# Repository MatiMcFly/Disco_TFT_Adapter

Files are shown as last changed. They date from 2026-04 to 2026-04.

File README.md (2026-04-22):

# 🖥️ Discovery Board TFT Adapter

This project contains the KiCad hardware design for a TFT display adapter designed to connect a TFT panel (GX040R-30MB-A1ICNL9707) to an STMicroelectronics STM32H747I Discovery Kit.

The adapter board includes circuitry to interface the display with the Discovery board, including a TPS61169 LED driver for the display backlight.

## 🔌 Connectivity between DISCO board and GX040R display

- according to the manufacturer, the display has to be connected as follows: Board (DP/N0) to LCD (DP/N1) and (DP/N1) to (DP/N3). A previous revision A of this board has gotten this wrong. D0 of the board has been connected to D0 of the TFT and D1 of the board to D1 of the TFT.
- CTP (capacitive touch display) functionalities (I2C, INT, ...) are not used

## 📚 Datasheets and Documentation

All relevant datasheets, manuals, and reference documents can be found in this [Google Drive folder](https://drive.google.com/drive/folders/1Etk3SSePW-oP0WRn9YrgEl5WCk2nYt2u?usp=sharing).

### 📋 Document Overview:

* **`disco_tft_adapter.pdf`** - The schematic for this adapter board project.
* **`GX040R-30MB-A1(V1).pdf`** - Datasheet for the TFT display panel used with this adapter.
* **`ICNL_9707_Datasheet...pdf`** - Datasheet for the ICNL9707, the display driver IC integrated into the TFT panel (might be obsolete)
* **`tps61169.pdf`** - Datasheet for the Texas Instruments TPS61169, the WLED driver IC used on this adapter for the display backlight.
* **`stm32h747-datasheet.pdf`** - Electrical characteristics and pinout for the STM32H747 microcontroller.
* **`stm32h747-ref-manual.pdf`** - Detailed reference manual for the STM32H747 MCU peripherals and registers.
* **`stm32h747-prog-manual.pdf`** - Programming manual detailing the architecture and instruction set for the STM32H747.
* **`mb1166-default-a09-schematic.pdf`** - Schematic for the MB1166 base board of the STM32H7 Discovery kit.
* **`mb1248-h747i-d03-schematic.pdf`** - Schematic for the MB1248 CPU board of the STM32H747I-DISCO kit.
* **`um2411-discovery-kit-...pdf`** - Official user manual (UM2411) for the STM32H747I-DISCO Discovery kit.
* **`JD9365DA-H3_User_Guide_Preliminary_V0.00_20200827.pdf` - User guide for the display driver. This is the last version that was received from the contact person at the display manufacturer.

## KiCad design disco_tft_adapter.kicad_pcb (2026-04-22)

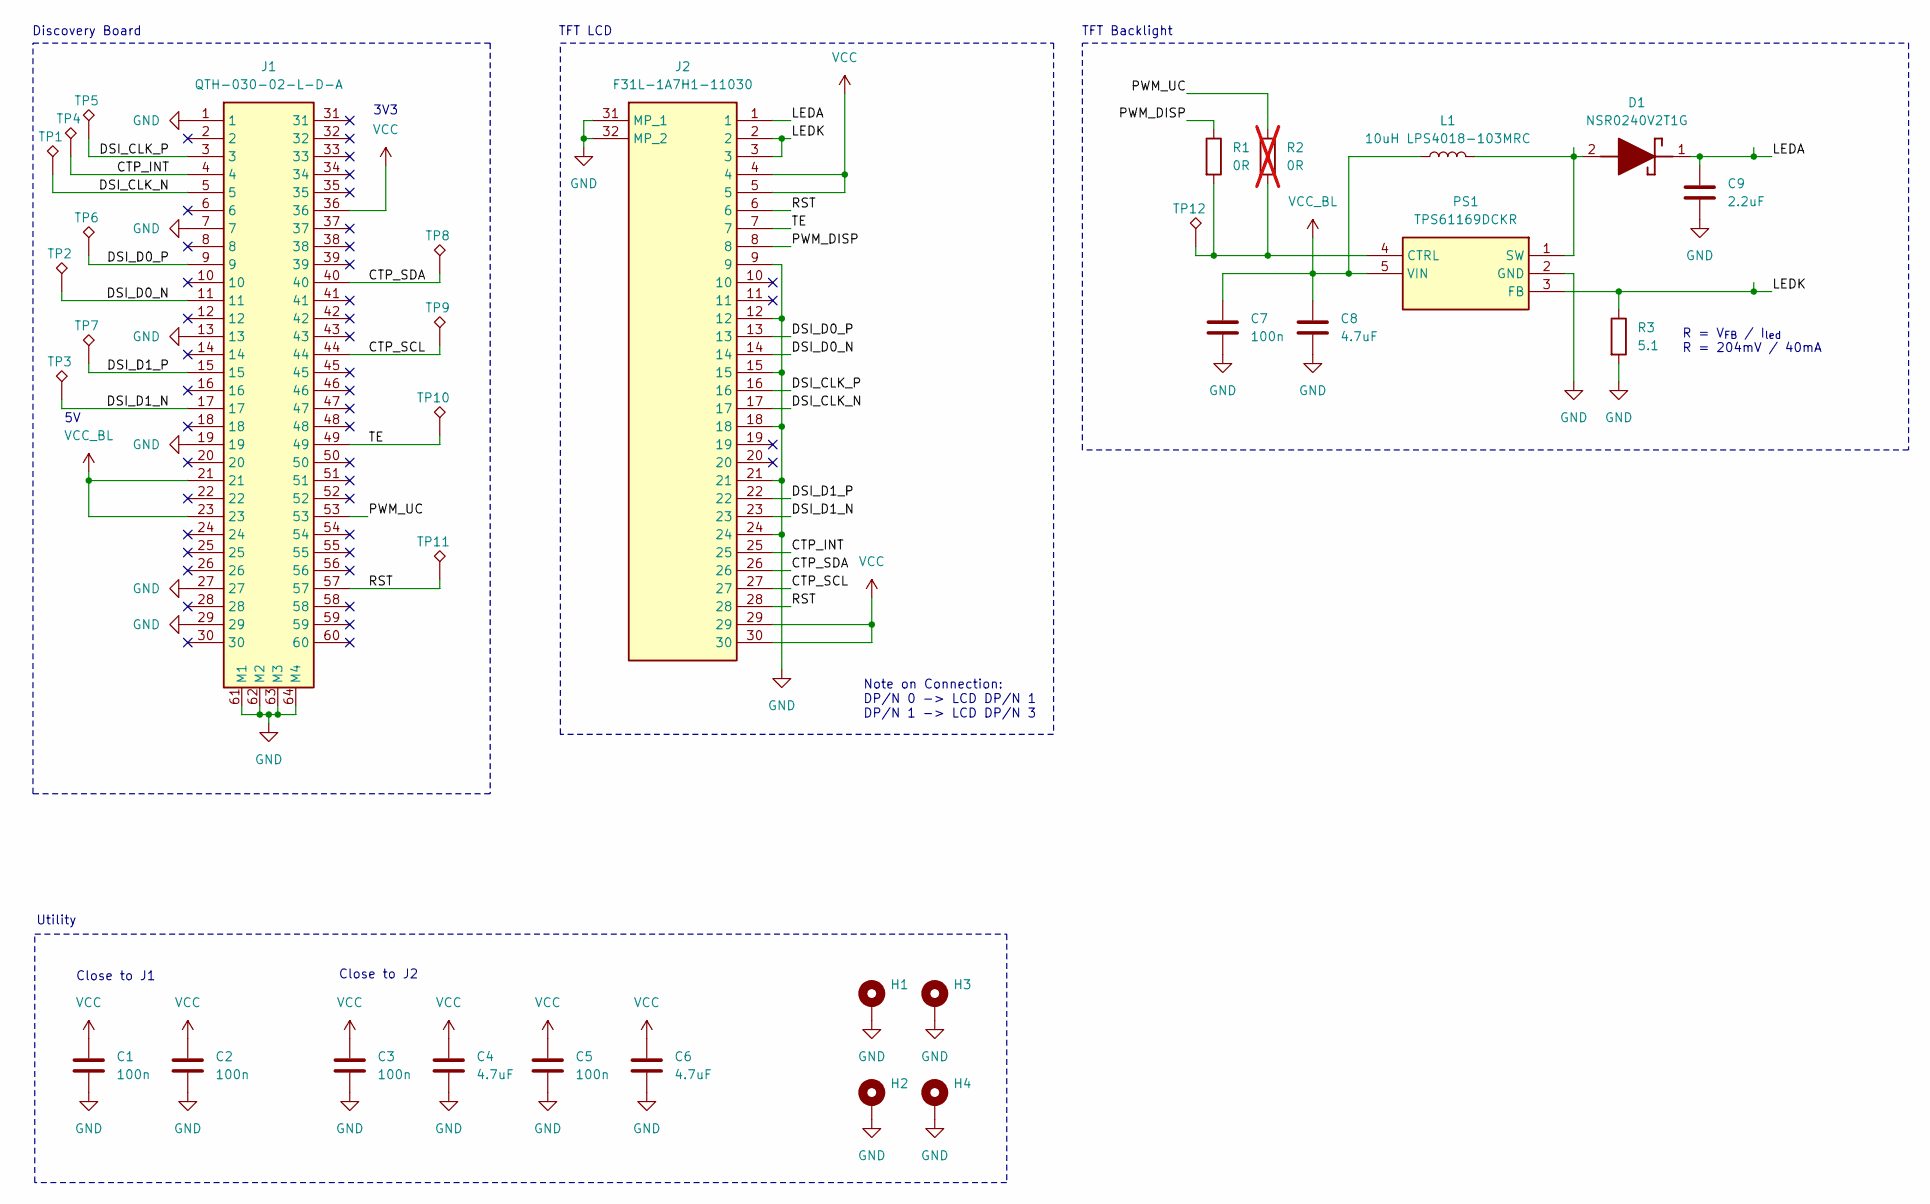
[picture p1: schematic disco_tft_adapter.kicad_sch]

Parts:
C1, C2, C3, C5, C7: 100n; C_0603_1608Metric; Mouser Part Number 603-C0603MRY5V9BB104
C4, C6, C8: 4.7uF; C_0805_2012Metric_Pad1.18x1.45mm_HandSolder; Mouser Part Number 581-08055D475KAT2A
C9: 2.2uF; C_0805_2012Metric_Pad1.18x1.45mm_HandSolder; Mouser Part Number 603-CC805KKX5R9BB225
D1: NSR0240V2T1G; SODFL1608X70N; Mouser Part Number 863-NSR0240V2T1G
H1, H2, H3, H4: MountingHole_Pad; MountingHole_4.5mm_Pad_TopBottom
J1: QTH-030-02-L-D-A; QTH-030-XX-Y-D-A; Mouser Part Number 200-QTH03002LDA
J2: F31L-1A7H1-11030; F31L1A7H111030; Mouser Part Number 649-F31L-1A7H1-11030
L1: 10uH LPS4018-103MRC; L_Coilcraft_1515SQ-47N; Mouser Part Number 994-LPS4018-103MRC
PS1: TPS61169DCKR; SOT65P210X110-5N; Mouser Part Number 595-TPS61169DCKR
R1: 0R; R_0603_1608Metric; Mouser Part Number 71-RCA06030000ZSEASR
R2: 0R; R_0603_1608Metric; Mouser Part Number 71-RCA06030000ZSEASR; not fitted
R3: 5.1; R_1206_3216Metric; Mouser Part Number 71-CRCW12065R10FKEA
TP1, TP2, TP3, TP4, TP5, TP6, TP7, TP8, TP9, TP10, TP11, TP12: TestPoint_Alt; TestPoint_TP_D0.5mm

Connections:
/CTP_INT: J1.4, J2.25, TP4.1 (1_1)
/CTP_SCL: J1.44, J2.27, TP9.1 (1_1)
/CTP_SDA: J1.40, J2.26, TP8.1 (1_1)
/DSI_CLK_N: J1.5, J2.17, TP1.1 (1_1)
/DSI_CLK_P: J1.3, J2.16, TP5.1 (1_1)
/DSI_D0_N: J1.11, J2.14, TP2.1 (1_1)
/DSI_D0_P: J1.9, J2.13, TP6.1 (1_1)
/DSI_D1_N: J1.17, J2.23, TP3.1 (1_1)
/DSI_D1_P: J1.15, J2.22, TP7.1 (1_1)
/LEDA: C9.1, D1.1 (K), J2.1
/LEDK: J2.2, J2.3, PS1.3 (FB), R3.1
/PWM_DISP: J2.8, R1.1
/PWM_UC: J1.53, R2.1
/RST: J1.57, J2.6, J2.28, TP11.1 (1_1)
/TE: J1.49, J2.7, TP10.1 (1_1)
GND: C1.2, C2.2, C3.2, C4.2, C5.2, C6.2, C7.2, C8.2, C9.2, H1.1 (1_1), H2.1 (1_1), H3.1 (1_1), H4.1 (1_1), J1.1, J1.7, J1.13, J1.19, J1.27, J1.29, J1.61 (M1), J1.62 (M2), J1.63 (M3), J1.64 (M4), J2.9, J2.12, J2.15, J2.18, J2.21, J2.24, J2.31 (MP_1), J2.32 (MP_2), PS1.2 (GND), R3.2
unnamed: D1.2 (A), L1.2, PS1.1 (SW)
unnamed: PS1.4 (CTRL), R1.2, R2.2, TP12.1 (1_1)
VCC: C1.1, C2.1, C3.1, C4.1, C5.1, C6.1, J1.36, J2.4, J2.5, J2.29, J2.30
VCC_BL: C7.1, C8.1, J1.21, J1.23, L1.1, PS1.5 (VIN)

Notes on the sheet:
3V3
Close to J1
Discovery Board
Close to J2
TFT Backlight
R = V_{FB} / I_{led} R = 204mV / 40mA
TFT LCD
Note on Connection: DP/N 0 -> LCD DP/N 1 DP/N 1 -> LCD DP/N 3
Utility

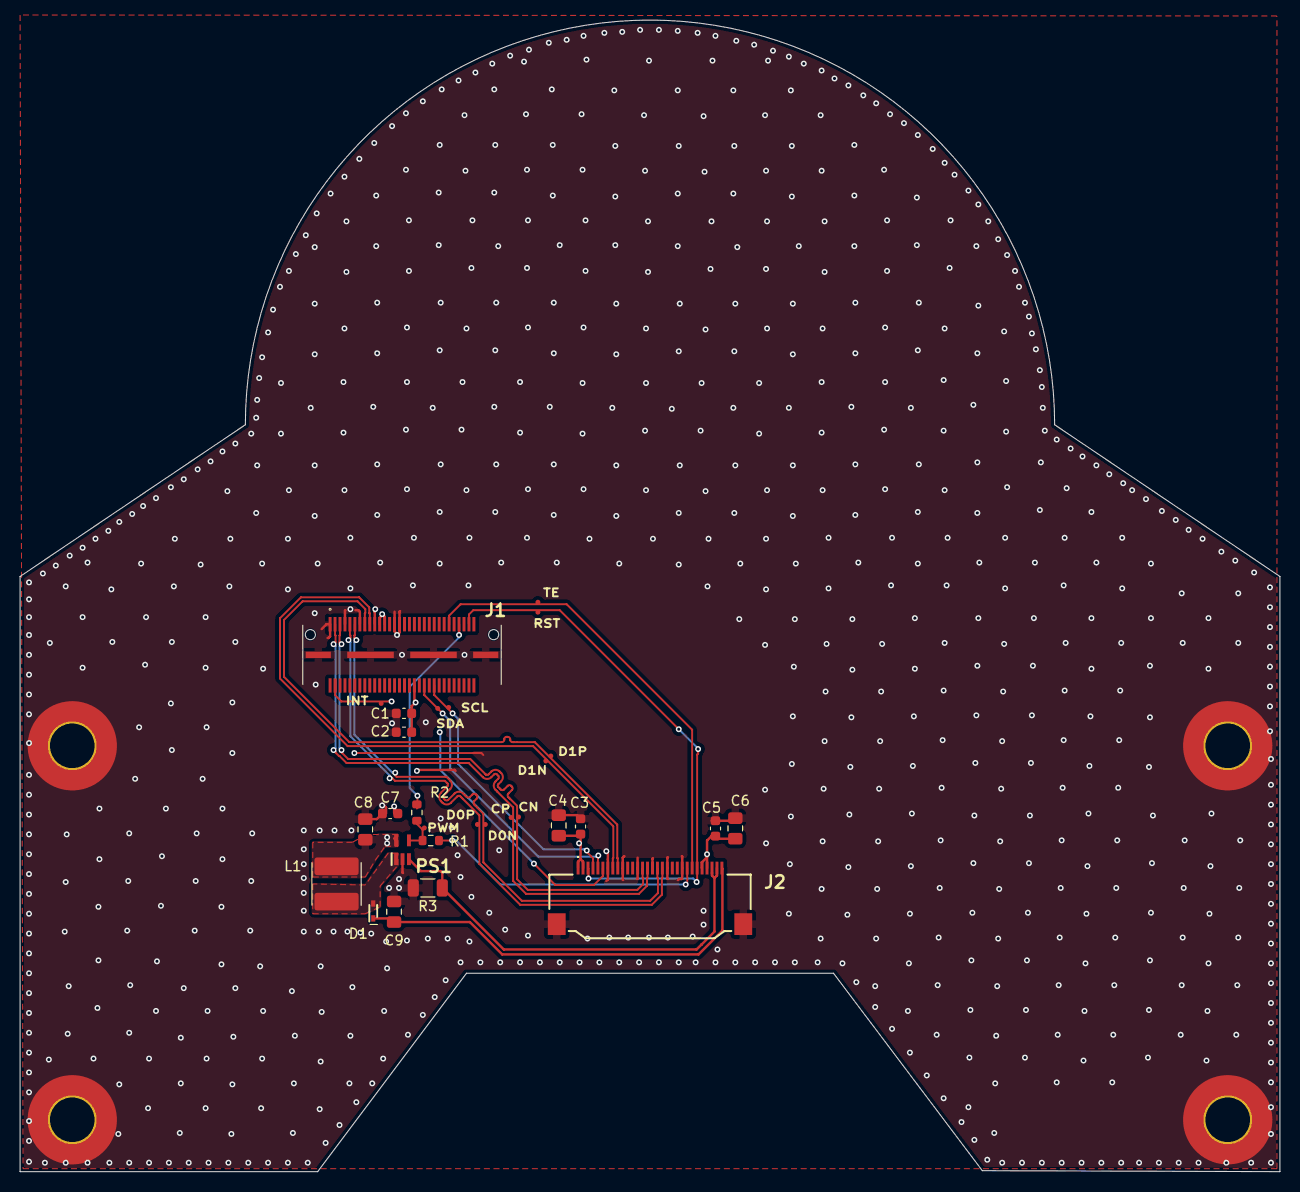
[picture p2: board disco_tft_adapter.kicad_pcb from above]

Board: 4 copper layers, 127.0 x 116.1 mm, 33 parts (0 on the bottom side), 20 nets.

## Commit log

2025-12-26 [library] add 30p qth plug used to connect with the disco board
2025-12-26 [schematics] addded connectors and adapter wiring
    [disco_tft_adapter.kicad_sch]
2025-12-31 [library] mod: updated QTH connector to include ground shield (pins 61 ... 64)
2025-12-31 [schematics] add: buck converter for backlight control
    [disco_tft_adapter.kicad_sch]
2026-01-02 [schematics] add: mounting holes
    [disco_tft_adapter.kicad_sch]
2026-01-02 [layout] add: initial component placement, ground pours
    [disco_tft_adapter.kicad_pcb]
2026-01-02 [layout] add: stitching vias, planes updated, routed buck converter for LED BL, added power labels to buck converter in schematics
    [disco_tft_adapter.kicad_pcb, disco_tft_adapter.kicad_sch]
2026-01-02 [schematics] add: more decoupling C
    [disco_tft_adapter.kicad_sch]
2026-01-02 [layout] updated board shape, finished initial routing
    [disco_tft_adapter.kicad_pcb]
2026-01-02 [layout] some adjustments, add pcb name + t3 logo
    [disco_tft_adapter.kicad_pcb]
2026-01-02 [project] ready up for production, added more infos for bom
    [disco_tft_adapter.kicad_pcb, disco_tft_adapter.kicad_sch]
2026-01-02 [layout] some finishing touches after gerber review
    [disco_tft_adapter.kicad_pcb]
2026-04-22 [proj] update to KiCAD 10.0
    [disco_tft_adapter.kicad_sch]
2026-04-22 [schematics] update wiring acc to communication with display manufacturer
    [disco_tft_adapter.kicad_sch]
2026-04-22 [lib] correct ffc connector numbering
2026-04-22 [schematic] update footprints of small C and R to 0603
    [disco_tft_adapter.kicad_sch]
2026-04-22 [layout] update footprints, clear routing for tft connector
    [disco_tft_adapter.kicad_pcb]
2026-04-22 [layout] route display TFT plug
    [disco_tft_adapter.kicad_pcb]
2026-04-22 [all] add test points using a custom footprint
    [disco_tft_adapter.kicad_pcb, disco_tft_adapter.kicad_sch]
2026-04-22 [layout] fixed DRC, added custom rule for J1
    [disco_tft_adapter.kicad_pcb]
2026-04-22 [layout] added labels for all test points
    [disco_tft_adapter.kicad_pcb]
